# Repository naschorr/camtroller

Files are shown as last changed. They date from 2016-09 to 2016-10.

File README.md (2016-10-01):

# camtroller
OctoPrint plugin (with CLI) that lets you move and rotate your webcam

Note: This project is designed around the [28BYJ-48 stepper motor and ULN2003 driver board](https://smile.amazon.com/USPRO-Stepper-28BYJ-48-4-Phase-ULN2003/dp/B00JB22IQC). It should also work for other steppers and drivers, however you'll probably have to tweak some stuff. 

Another Note: Actual handy plugin installation and functionality is coming soon. For now, feel free to use these config settings to manipulate your webcam from the web interface's "System" dropdown.

Also check out my [other OctoPrint script](https://github.com/naschorr/octopi-webcam-toggle) for toggling your webcam from the web interface!

## Installation
- `git clone` this repo into your `~/scripts/` directory on your OctoPi
  - Alternatively, just drop `camtroller.py` into your `~/scripts/` directory.
- Insert the lines from `camtroller.yaml` into the `~/.octoprint/config.yaml` file under the `system:` `actions:` section. (See below image)
  - If you did just put `camtroller.py` into the scripts directory, then you'll have to remove the `/camtroller` subdirectory from the  the `command:` lines in `camtroller.yaml`.

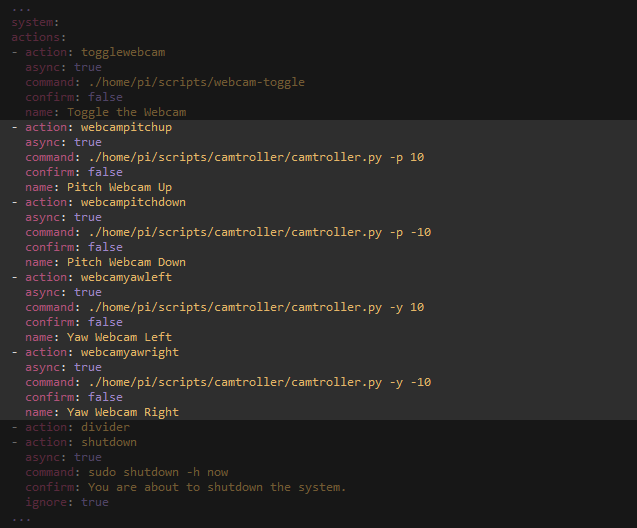
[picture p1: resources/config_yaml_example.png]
config.yaml example


## Usage
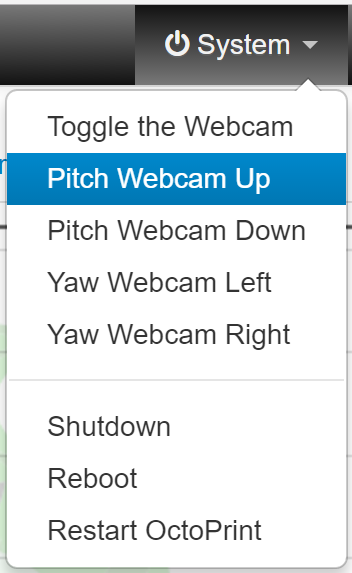
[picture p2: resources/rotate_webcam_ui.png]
rotate webcam example


At the top of the page, just click on the 'System' dropdown. Then, hit any of the pitch or yaw buttons to rotate the webcam. Check out the 'Control' tab to see the changes. If you're not seeing anything, make sure that the mjpg_streamer is configured and running (configs located in `/boot/octopi.txt`, and `sudo service webcamd restart` respectively).

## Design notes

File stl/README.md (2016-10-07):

# camtroller
OctoPrint plugin (with CLI) that lets you move and rotate your webcam

## STL Files
It should again be noted that these STL files are mostly designed around the 28BYJ-48 stepper motor, the Raspberry Pi Camera. So you might want roll your own solution if you plan on using a different webcam, or stepper motor. Currently, the "frame mount.stl" and "stepper driver case.stl" files are designed for a Wanhao Duplicator i3, with the [Z-Brace mod](http://www.thingiverse.com/thing:921948).

## Assembly
Note that this is far from the final version. For now, here is a render of what the assembled STL files looks like.
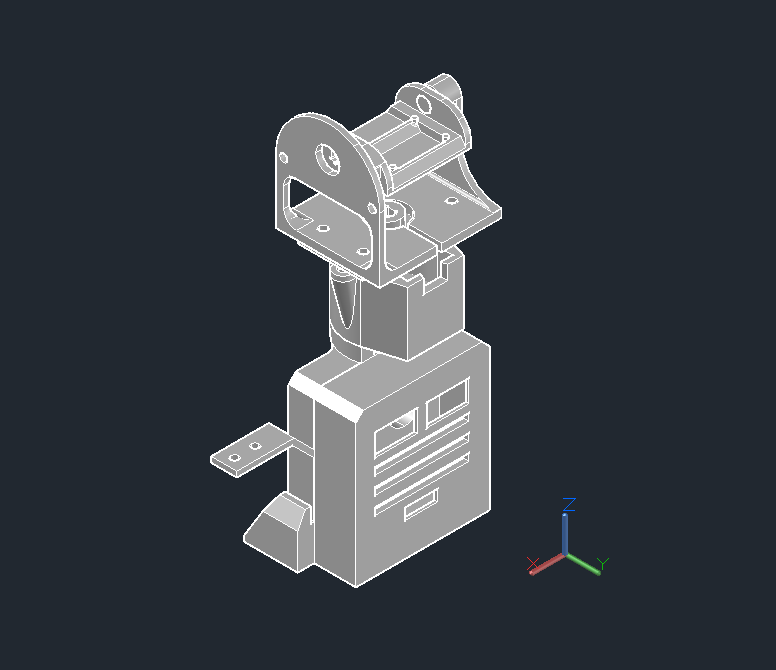
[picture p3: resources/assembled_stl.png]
assembled stl render


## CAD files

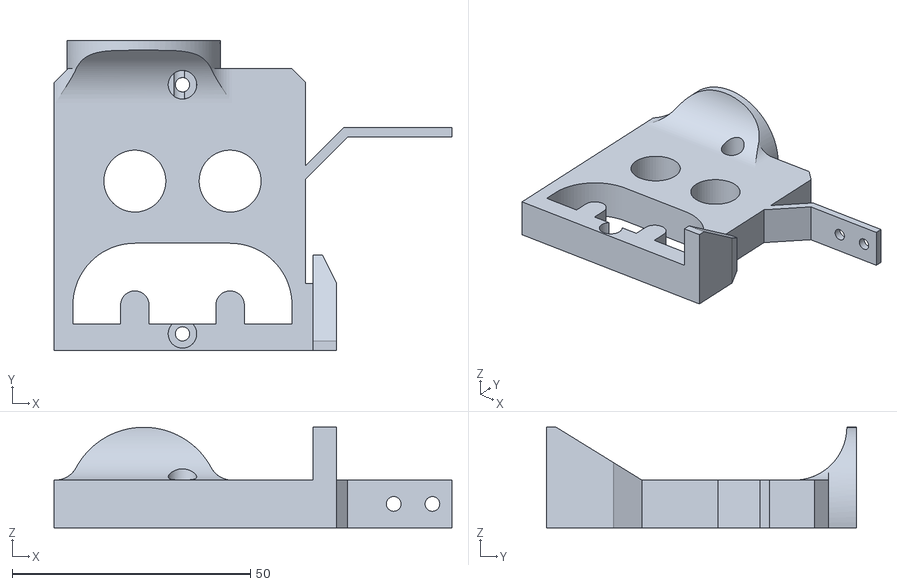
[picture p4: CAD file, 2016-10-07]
stl/frame mount.stl
83.6 x 65.0 x 21.1

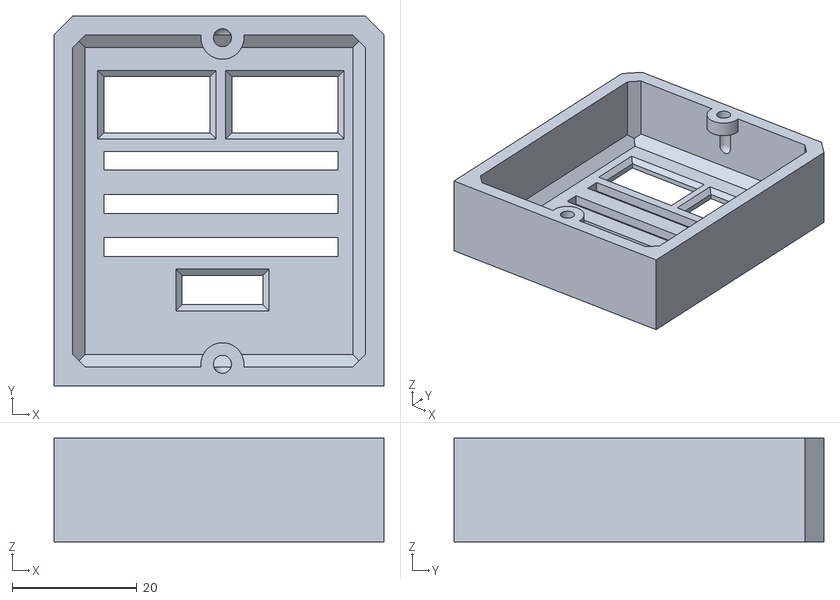
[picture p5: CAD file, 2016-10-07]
stl/stepper driver case.stl
52.8 x 59.2 x 16.6

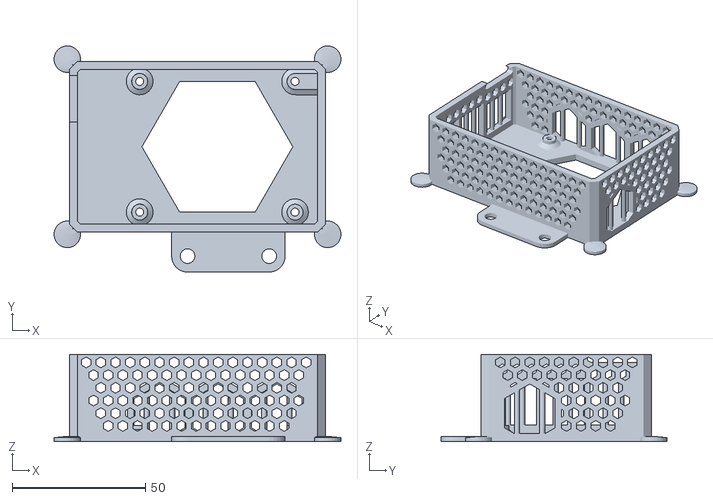
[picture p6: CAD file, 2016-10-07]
stl/raspberry pi case.stl
107.6 x 84.8 x 32.7

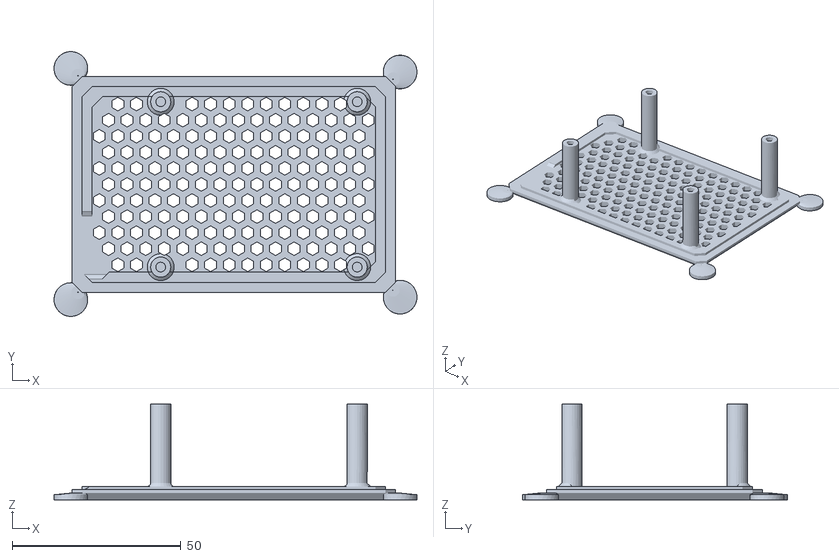
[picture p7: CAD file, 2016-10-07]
stl/raspberry pi case lid.stl
107.6 x 78.5 x 28.3

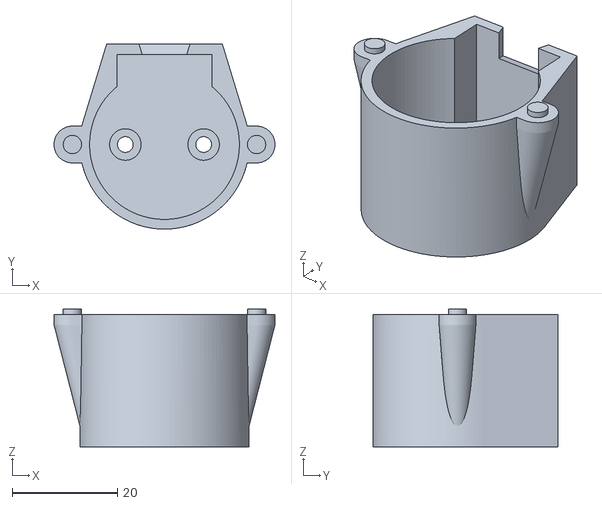
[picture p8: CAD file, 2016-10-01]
stl/yaw stepper mount.stl
42.0 x 35.2 x 26.2

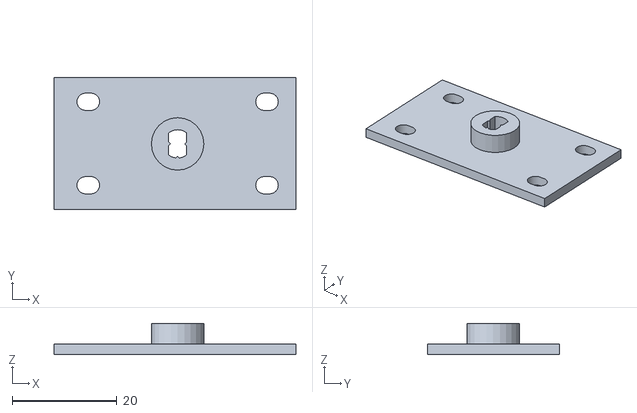
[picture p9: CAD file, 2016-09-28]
stl/yaw stepper attachment.stl
46.1 x 25.2 x 6.00

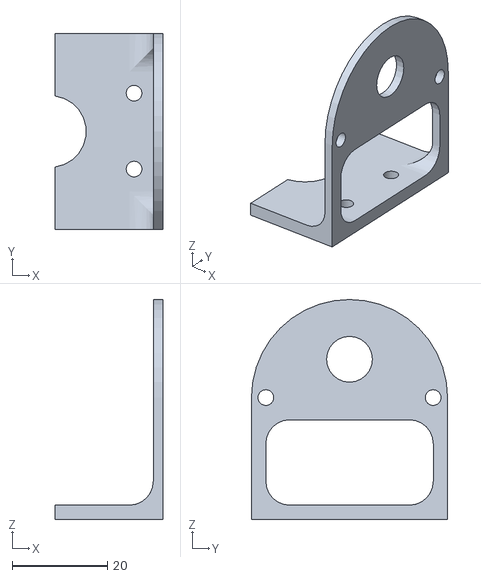
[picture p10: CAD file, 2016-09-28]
stl/pitch stepper mount.stl
22.6 x 41.1 x 46.1

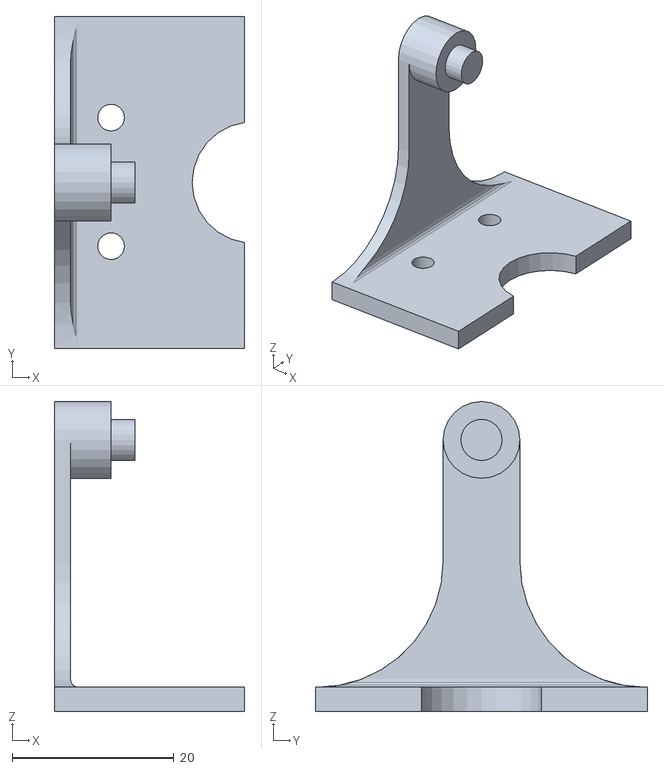
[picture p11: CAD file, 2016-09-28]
stl/pitch support mount.stl
23.6 x 41.1 x 38.3

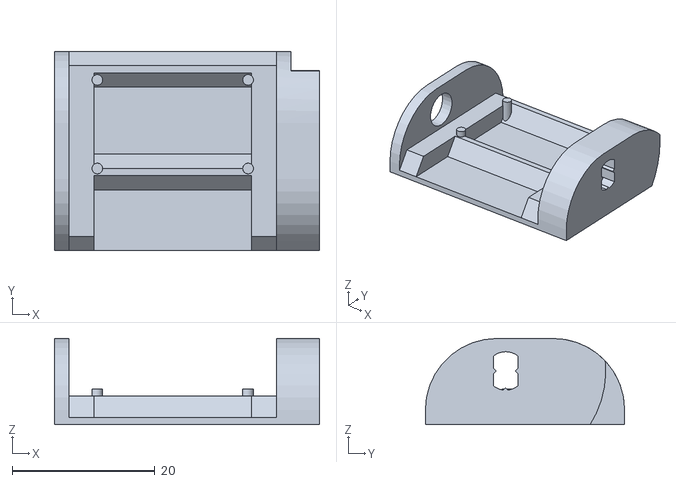
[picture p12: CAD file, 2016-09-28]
stl/camera mount.stl
37.1 x 27.9 x 12.1

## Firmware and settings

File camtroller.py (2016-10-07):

#!/usr/bin/python

from __future__ import print_function, division

def printErr(desc, error):
	print('{0} Error: "{1}"'.format(desc, error))

import sys
try:
	import RPi.GPIO as GPIO
except ImportError as ie:
	printErr("Unable to import GPIO module. You might need sudo permissions.", ie)
	sys.exit()
import time
import threading
import click

## String literals
BOARD = "board"
BCM = "bcm"

## Defaults
FULL_REV_TIME = 10	# Time to complete full revolution (ideally)
DIR = 1			# 1 for CW, -1 for CCW
PIN_MODE = BOARD 	# Default pin mode identifier (not the actual pin mode)
PITCH_PINS = (40, 38, 36, 32)
YAW_PINS = (37, 35, 33, 31)

class StepperController:
	STEPS_PER_REV = 4076		# 28byj-48 Stepper
	STEP_PHASES =  [[1,0,0,1],	# Half stepping on ULN2003
					[1,0,0,0],
					[1,1,0,0],
					[0,1,0,0],
					[0,1,1,0],
					[0,0,1,0],
					[0,0,1,1],
					[0,0,0,1]]
	WAIT_TIME = FULL_REV_TIME/STEPS_PER_REV

	def __init__(self, pins):
		self.thisPhase = 0
		self.pins = pins

	@property
	def thisPhase(self):
		return self._thisPhase

	@thisPhase.setter
	def thisPhase(self, value):
		self._thisPhase = value

	@property
	def pins(self):
		return self._pins

	@pins.setter
	def pins(self, value):
		self._pins = value

	def doStep(self, direction=DIR):
		currentSteps = self.STEP_PHASES[self.thisPhase]
		for pin in range(len(self.pins)):
			GPIO.output(self.pins[pin], currentSteps[pin])

		self.thisPhase = (self.thisPhase + direction) % len(self.STEP_PHASES)

	def stepDegrees(self, degrees, waitTime=WAIT_TIME):
		steps = int((self.STEPS_PER_REV/360.0) * abs(degrees))
		direction = 1 if degrees > 0 else -1
		for stepIndex in range(steps):
			self.doStep(direction)
			time.sleep(waitTime)

	def threadedStepDegrees(self, degrees, waitTime=WAIT_TIME):
		thread = threading.Thread(target=self.stepDegrees, args=(degrees, waitTime))
		thread.start()
		return thread


def init(pin_mode, yaw_pins, pitch_pins):
	if(pin_mode == BCM):
		GPIO.setmode(GPIO.BCM)		
	else:	# Otherwise it's in board mode.
		GPIO.setmode(GPIO.BOARD)

	try:
		GPIO.setup(pitch_pins, GPIO.OUT)
	except ValueError as ve:
		printErr("The supplied pitch stepper pins {0} are invalid. Defaulting to pins {1}. Consult the pinout, and make sure your pin-mode is correct.".format(pitch_pins, PITCH_PINS), ve)
		pitch_pins = PITCH_PINS
		GPIO.setup(PITCH_PINS, GPIO.OUT)

	try:
		GPIO.setup(yaw_pins, GPIO.OUT)
	except ValueError as ve:
		printErr("The supplied yaw stepper pins {0} are invalid. Defaulting to pins {1}. Consult the pinout, and make sure your pin-mode is correct.".format(yaw_pins, YAW_PINS), ve)
		yaw_pins = YAW_PINS
		GPIO.setup(YAW_PINS, GPIO.OUT)

	## Return successfully initialized StepperController objects (with consistent pins!)
	return StepperController(yaw_pins), StepperController(pitch_pins)


@click.command()
@click.option('--yaw', '-y', type=float, help='Number of degrees to yaw the camera left (or right if negative).')
@click.option('--pitch', '-p', type=float, help='Number of degrees to pitch the camera up (or down if negative).')
@click.option('--pin-mode', default=PIN_MODE, type=click.Choice([BOARD, BCM]), help='Selects the pin selection mode. Defaults to {0}.'.format(PIN_MODE))
@click.option('--yaw-pins', default=YAW_PINS, type=(int, int, int, int), help='Pins to control the yaw stepper. Defaults to {0}.'.format(YAW_PINS))
@click.option('--pitch-pins', default=PITCH_PINS, type=(int, int, int, int), help='Pins to control the pitch stepper. Defaults to {0}.'.format(PITCH_PINS))
def main(yaw, pitch, pin_mode, yaw_pins, pitch_pins):
	yawStepper, pitchStepper = init(pin_mode, yaw_pins, pitch_pins)

	try:
		if(yaw and pitch):
			yawStepper.stepDegrees(yaw)
			pitchStepper.threadedStepDegrees(pitch).join()
		elif(yaw):
			yawStepper.stepDegrees(yaw)
		elif(pitch):
			pitchStepper.stepDegrees(pitch)
		else:
			print("No yaw or pitch argument supplied.")
	except KeyboardInterrupt as ki:
		printErr("Interrupt detected. Going to clean up the GPIO and exit.", ki)
	finally:
		GPIO.cleanup()
		sys.exit()


if(__name__ == "__main__"):
	main()

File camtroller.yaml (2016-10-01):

  - action: webcampitchup
    async: true
    command: ./home/pi/scripts/camtroller/camtroller.py -p 10
    confirm: false
    name: Pitch Webcam Up
  - action: webcampitchdown
    async: true
    command: ./home/pi/scripts/camtroller/camtroller.py -p -10
    confirm: false
    name: Pitch Webcam Down
  - action: webcamyawleft
    async: true
    command: ./home/pi/scripts/camtroller/camtroller.py -y 10
    confirm: false
    name: Yaw Webcam Left
  - action: webcamyawright
    async: true
    command: ./home/pi/scripts/camtroller/camtroller.py -y -10
    confirm: false
    name: Yaw Webcam Right

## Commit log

2016-09-28 Initial commit
    - The basic CLI works, and the camera reliably pitches and yaws.
2016-09-28 Added basic camera and stepper mount STLs
    [bottom stepper mount.stl, camera mount plate.stl, vertical non stepper mount.stl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]
2016-09-28 Refactoring and improved error output
    - Fixed some broken indentation, that wasn't being caught on my Raspberry Pi
    - Added a dedicated function to handle error printing (and eventually error logging)
    [camtroller.py]
2016-09-29 Fixed WAIT_TIME float calculation bug
    - Python was performing the normal int truncated division, and my float conversion came after division, instead of before. Easy.
    [camtroller.py]
2016-10-01 Added basic controls to the web interface
    - Added some example images of the ui, and the changes needed to config.yaml
    - Added a couple more mounting STLs for the 28byj-48 stepper
    [mounting arm.stl, mounting cup.stl]
2016-10-07 Added additional STL files used in the project
    - Renamed all of the existing STL files to better describe them
    - Added render of the assembled camera mounting system (sans electronics)
    [camera mount.stl, frame mount.stl, mounting arm.stl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]
